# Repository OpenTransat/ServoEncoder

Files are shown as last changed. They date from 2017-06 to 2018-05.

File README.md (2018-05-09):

# ServoEncoder
Controls a motor by evaluating position feedback from a magnetic encoder

## Features

* Based on Atmega328P @ 2 MHz

* Absolute magnetic rotary encoder EMS22A is mounted on the PCB

* Used with JGY-2838 or a similar motor controlled by a two-wire interface

* The two-wire output can be used as serial RX/TX for debugging

* One can use a stepper motor by connecting the two-wire output to a stepper motor driver

* PWM input like a typical servo or serial input (serial version has been chosen as it's more precise than reading the pulse length)

* It provides a feedback to the main controller to determine if the motor is overloaded or stuck

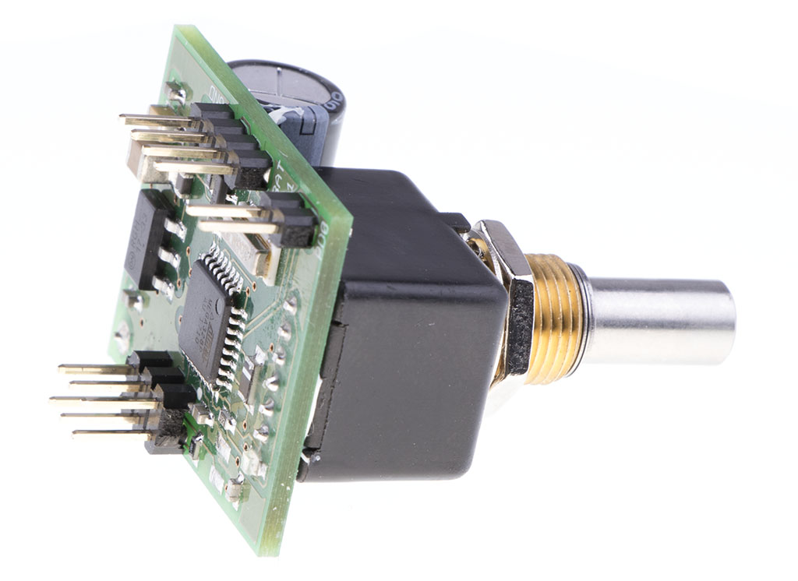
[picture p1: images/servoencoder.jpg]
ServoEncoder PCB


It has been designed as a robust solution for steering the rudder on autonomous boat. The life span has been tested with a worm geared motor JGY-2838.

Ongoing test: 2 million cycles

## Video: Testing worm drive life span

Testing worm drive life span (https://www.youtube.com/watch?v=ynh-ik3KGtM)

## Video: The actual application

Rudder control: Worm geared motor with a position feedback (https://www.youtube.com/watch?v=95Na8EOg1Mo)

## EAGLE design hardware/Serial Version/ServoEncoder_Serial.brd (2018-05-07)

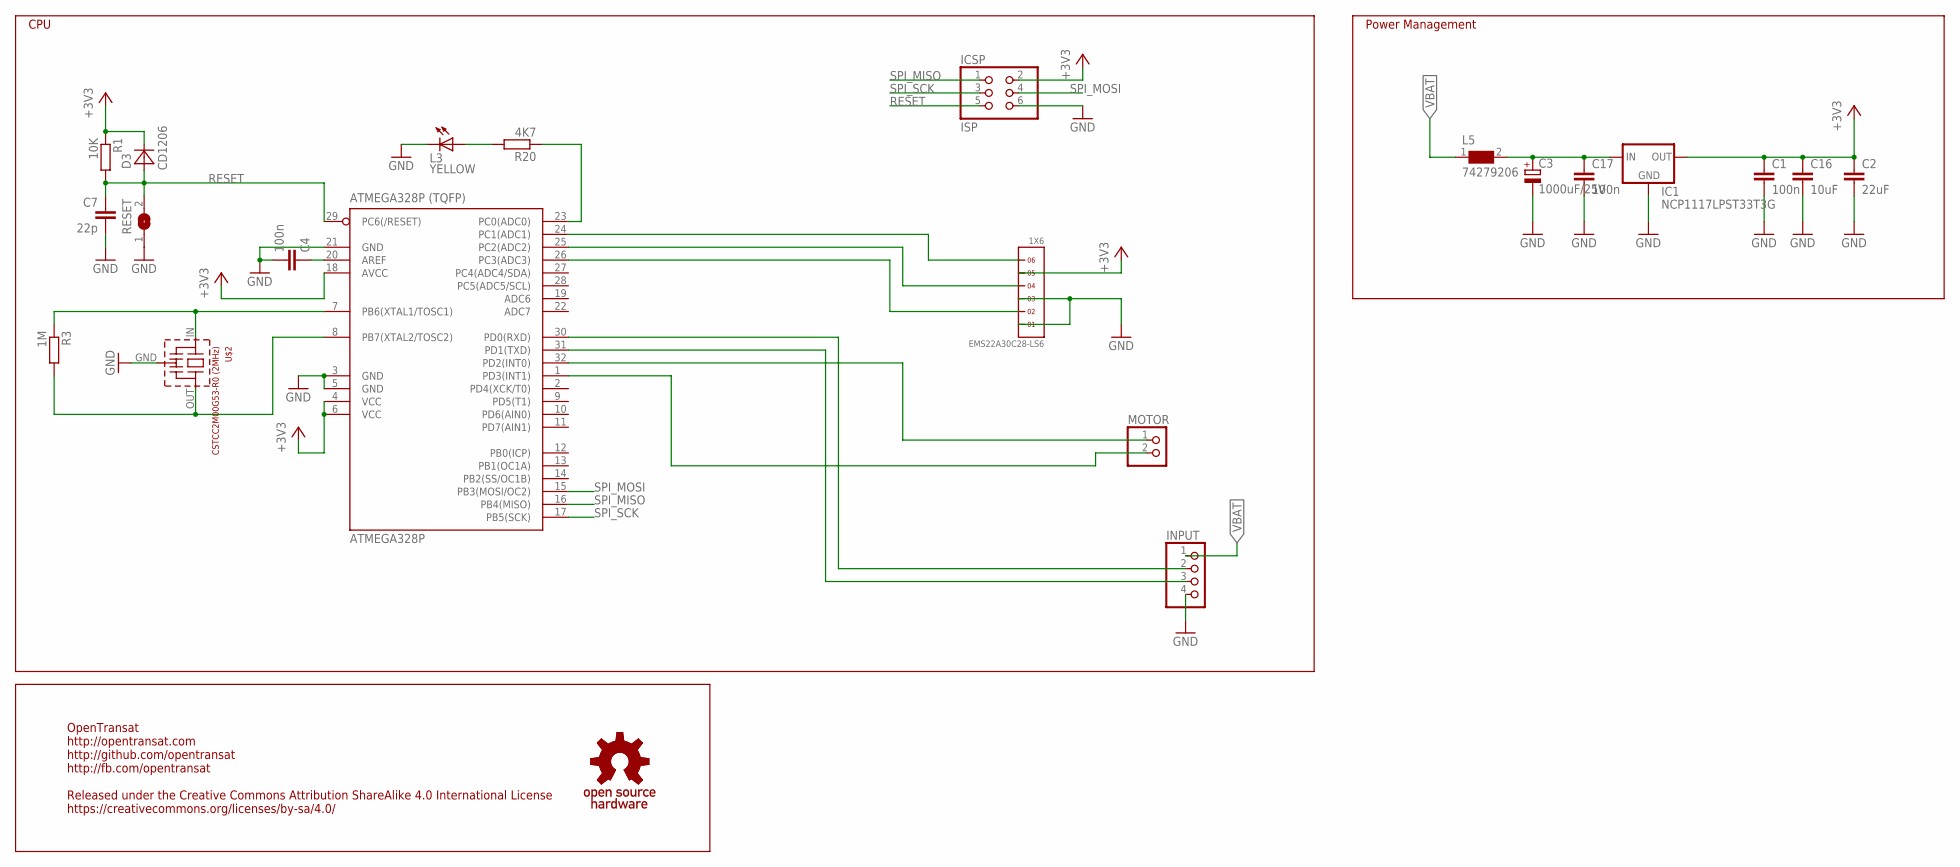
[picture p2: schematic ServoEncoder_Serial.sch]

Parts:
ATMEGA328P: ATMEGA328P (TQFP); TQFP32-08
C1, C4, C17: 100n; C0603
C2: 22uF; C1210
C3: 1000uF/25V; E5-10,5
C7: 22p; C0603
C16: 10uF; C1206
D3: CD1206; R1206
EMS22A30C28-LS6: 1X6
IC1: NCP1117LPST33T3G; SOT223
ICSP: ISP; 2X03
INPUT: PINHD-1X4; 1X04
L3: YELLOW; CHIPLED_0805
L5: 74279206; 0805
MOTOR: PINHD-1X2; 1X02
R1: 10K; R0603
R3: 1M; R0603
R20: 4K7; R0603
RESET: SJW
U$1: OSHW_S; OSHWS
U$2: CSTCC2M00G53-R0 (2MHz); CSTCC

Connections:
+3V3: ATMEGA328P.4 (VCC), ATMEGA328P.6 (VCC), ATMEGA328P.18 (AVCC), C1.1, C2.1, C16.1, D3.2 (C), EMS22A30C28-LS6.5, IC1.2 (OUT), IC1.4 (OUT), ICSP.2, R1.1
AREF: ATMEGA328P.20 (AREF), C4.1
GND: ATMEGA328P.3 (GND), ATMEGA328P.5 (GND), ATMEGA328P.21 (GND), C1.2, C2.2, C3.-, C4.2, C7.2, C16.2, C17.2, EMS22A30C28-LS6.1, EMS22A30C28-LS6.3, IC1.1 (GND), ICSP.6, INPUT.4, L3.C, RESET.1, U$2.GND
L13: ATMEGA328P.23 (PC0(ADC0)), R20.1
unnamed: C3.+, C17.1, IC1.3 (IN), L5.2
unnamed: ATMEGA328P.30 (PD0(RXD)), INPUT.2
unnamed: L3.A, R20.2
unnamed: ATMEGA328P.31 (PD1(TXD)), INPUT.3
unnamed: ATMEGA328P.1 (PD3(INT1)), MOTOR.2
unnamed: ATMEGA328P.24 (PC1(ADC1)), EMS22A30C28-LS6.6
unnamed: ATMEGA328P.25 (PC2(ADC2)), EMS22A30C28-LS6.4
unnamed: ATMEGA328P.26 (PC3(ADC3)), EMS22A30C28-LS6.2
unnamed: ATMEGA328P.32 (PD2(INT0)), MOTOR.1
RESET: ATMEGA328P.29 (PC6(/RESET)), C7.1, D3.1 (A), ICSP.5, R1.2, RESET.2
SPI_MISO: ATMEGA328P.16 (PB4(MISO)), ICSP.1
SPI_MOSI: ATMEGA328P.15 (PB3(MOSI/OC2)), ICSP.4
SPI_SCK: ATMEGA328P.17 (PB5(SCK)), ICSP.3
VBAT: INPUT.1, L5.1
XTAL1: ATMEGA328P.8 (PB7(XTAL2/TOSC2)), R3.2, U$2.OUT
XTAL2: ATMEGA328P.7 (PB6(XTAL1/TOSC1)), R3.1, U$2.IN

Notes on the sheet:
OpenTransat http://opentransat.com http://github.com/opentransat http://fb.com/opentransat Released under the Creative Commons Attribution ShareAlike 4.0 International License https://creativecommons.org/licenses/by-sa/4.0/
Power Management
CPU

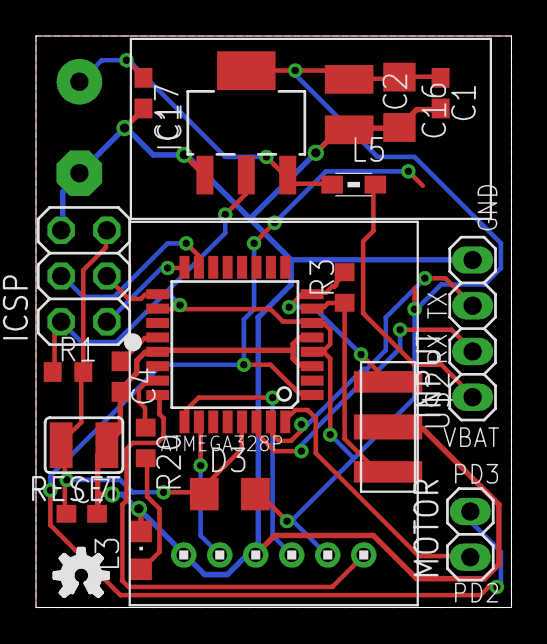
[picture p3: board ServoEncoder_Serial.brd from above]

Board: 2 copper layers, 26.4 x 31.8 mm, 22 parts (1 on the bottom side), 20 nets.

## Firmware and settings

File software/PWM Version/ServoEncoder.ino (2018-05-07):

/*
ServoEncoder
https://github.com/OpenTransat/ServoEncoder

Released under the Creative Commons Attribution ShareAlike 4.0 International License
https://creativecommons.org/licenses/by-sa/4.0/
*/

#define SERIAL_DEBUG //switch between serial debug and motor
#define LED 14 //PC0
#define PIN_CS 15 //PC1, EMS:6
#define PIN_CLK 17 //PC3, EMS:2
#define PIN_DO 16 //PC2, EMS:4
#define PIN_ON 0 //PD0 = Serial RXD, active LOW
#define PIN_REV 1 //PD1 = Serial TXD, active LOW
#define PIN_PWM 2 //PD2
#define PIN_FB 3 //PD3
#define ENC_ZERO 127
#define ENC_MAXDIF 100
#define ENC_MIN (ENC_ZERO - ENC_MAXDIF) //max left
#define ENC_MAX (ENC_ZERO + ENC_MAXDIF) //max right
#define MINCHANGE 0 //minimum PWM change to prevent flickering, 32 is a typical measurement error
#define CORRECTION_LEFT (+11)
#define CORRECTION_RIGHT (-10)

#define PWM_PULSES 3
#define PWM_VALID_THRESHOLD 65 //all PWM_PULSES pulses in the pwm_pulse[] array must be equal within the PWM_VALID_THRESHOLD
volatile unsigned long pwm_timer_start = 0;
volatile unsigned int pwm_pulse[PWM_PULSES];
volatile unsigned char pwm_index = 0;
#define PWM_TIMEOUT 2500

int pulse;
int enc_goto;

void calcRC() { //blocking max 2.5ms
  if(digitalRead(PIN_PWM) == HIGH) { 
    pwm_timer_start = micros();
    unsigned int pwm_length;
    while(digitalRead(PIN_PWM) == HIGH) {
      pwm_length = (unsigned int)(micros() - pwm_timer_start); //negative number converted OK on micros() overflow
      if (pwm_length > PWM_TIMEOUT) //timeout
        return;
    }
    pwm_index = (++pwm_index) % PWM_PULSES;
    pwm_pulse[pwm_index] = (unsigned int)(micros() - pwm_timer_start);
  }
}

/*
void calcRC() { //non-blocking
  if(digitalRead(PIN_PWM) == HIGH) { 
    pwm_timer_start = micros();
  }
  else { 
    if(pwm_timer_start != 0) {
      pwm_index = (++pwm_index) % PWM_PULSES;
      pwm_pulse[pwm_index] = (unsigned int)(micros() - pwm_timer_start); //negative number converted OK on micros() overflow
      pwm_timer_start = 0;
    }
  }
}
*/

void setup() {
  pinMode(LED, OUTPUT);

  #ifdef SERIAL_DEBUG
    Serial.begin(9600); //9600 supported for 2MHz
  #else
    pinMode(PIN_ON, OUTPUT);
    digitalWrite(PIN_ON, HIGH);
    pinMode(PIN_REV, OUTPUT);
    digitalWrite(PIN_REV, HIGH);
  #endif

  pinMode(PIN_CS, OUTPUT);
  digitalWrite(PIN_CS, LOW);
  pinMode(PIN_CLK, OUTPUT);
  digitalWrite(PIN_CLK, HIGH);
  pinMode(PIN_DO, INPUT);

  pinMode(PIN_PWM, INPUT);
  pinMode(PIN_FB, OUTPUT);
  digitalWrite(PIN_FB, LOW);
  attachInterrupt(digitalPinToInterrupt(PIN_PWM), calcRC, CHANGE);
}

int enc_read() { //output: 0..1023, -1 = parity error
  digitalWrite(PIN_CS, HIGH);
  delayMicroseconds(1);
  digitalWrite(PIN_CS, LOW);
  byte b[16];
  int pos = 0;
  byte parity = 0;

  for (int i = 0; i < 16; i++) {
    digitalWrite(PIN_CLK, LOW);
    delayMicroseconds(1);
    digitalWrite(PIN_CLK, HIGH);
    b[i] = digitalRead(PIN_DO) == HIGH ? 1 : 0;

    if (i < 15)
      parity += b[i];
  }

  parity %= 2;

  if (b[15] == parity) {
    for (int i = 0; i < 10; i++) {
      pos += b[i] * (1 << 10-(i+1));
    }
    digitalWrite(PIN_CS, LOW);
    return pos;
  }
  digitalWrite(PIN_CS, LOW);
  return -1;
}

bool validPulse() {
  for (int i = 0; i < PWM_PULSES; i++) {
    if (abs((int)pwm_pulse[i] - (int)pwm_pulse[(i+1)%PWM_PULSES]) > PWM_VALID_THRESHOLD) {
      return false;
    }
  }
  return true;
}

bool isNewPulse() {
  if (!validPulse())
    return false;
  pulse = pwm_pulse[PWM_PULSES-1]; //save pwm_pulse from interrupts
//  pulse = ((millis() / 10000) % 4) * 500 + 1000; if (pulse > 2000) pulse = 1500; //simulation

  static int prev_pulse;

  #ifdef SERIAL_DEBUG
//    Serial.print(pulse);
  #endif

  if (pulse < 900 || pulse > 2100) { //bad pulse
    return false;
  }

  if (pulse < prev_pulse - MINCHANGE || pulse > prev_pulse + MINCHANGE) { //pulse is outside the safe interval
    prev_pulse = pulse;
    return true;
  }
  
  return false;
}

enum tstate {
  STATE_IDLE,
  STATE_RUNNING,
  STATE_NEWPULSE //move interrupted by a new pulse
};

tstate state = STATE_IDLE;

void loop() {
  if (isNewPulse() || state != STATE_IDLE) {
    int enc_goto = map(pulse, 1000, 2000, ENC_MIN, ENC_MAX);
    enc_goto = max(enc_goto, ENC_MIN);
    enc_goto = min(enc_goto, ENC_MAX);
    int enc_pos = enc_read();
    if (enc_pos > 0) { //encoder parity check OK
      #ifdef SERIAL_DEBUG
        Serial.print(pulse);
        Serial.print("\t");
        Serial.print(enc_goto);
        Serial.print("\t");
        Serial.print(enc_pos);
      #endif
      if (enc_pos > enc_goto) { //turn left
        state = STATE_RUNNING;
        #ifdef SERIAL_DEBUG
          Serial.println("\tturn left");
        #else
          motor_left();
        #endif
        while ((enc_pos = enc_read()) > enc_goto + CORRECTION_LEFT) {
          /*if (isNewPulse()) { //TO BE TESTED
            #ifdef SERIAL_DEBUG
              Serial.println("Interrupted by a new pulse");
            #endif
            state = STATE_NEWPULSE;
            break;
          }*/
        }
        if (state != STATE_NEWPULSE) {
          #ifdef SERIAL_DEBUG
            Serial.println("Stop");
          #else
            motor_stop();
          #endif        
          state = STATE_IDLE;
        }
      }
      else if (enc_pos < enc_goto) { //turn right
        state = STATE_RUNNING;
        #ifdef SERIAL_DEBUG
          Serial.println("\tturn right");
        #else
          motor_right();
        #endif
        while ((enc_pos = enc_read()) < enc_goto + CORRECTION_RIGHT) {
          /*if (isNewPulse()) { //TO BE TESTED
            #ifdef SERIAL_DEBUG
              Serial.println("Interrupted by a new pulse");
            #endif
            state = STATE_NEWPULSE;
            break;
          }*/
        }
        if (state != STATE_NEWPULSE) {
          #ifdef SERIAL_DEBUG
            Serial.println("Stop");
          #else
            motor_stop();
          #endif        
          state = STATE_IDLE;
        }
      }
      else { //equal position => stop the motor
        #ifdef SERIAL_DEBUG
          Serial.println("Stop");
        #else
          motor_stop();
        #endif
        state = STATE_IDLE;
      }
    }
    else { //bad encoder parity check => stop the motor
      #ifdef SERIAL_DEBUG
        Serial.println("bad parity");
      #else
        motor_stop();
      #endif
      state = STATE_IDLE;      
    }
  }
}

void motor_stop() {
  digitalWrite(PIN_ON, HIGH);
  digitalWrite(PIN_REV, HIGH);
}

void motor_right() {
  digitalWrite(PIN_REV, HIGH);
  digitalWrite(PIN_ON, LOW);
}

void motor_left() {
  digitalWrite(PIN_REV, LOW);
  digitalWrite(PIN_ON, LOW);
}

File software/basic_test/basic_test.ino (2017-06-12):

/*
ServoEncoder
TEST PROGRAM

https://github.com/OpenTransat/ServoEncoder

Released under the Creative Commons Attribution ShareAlike 4.0 International License
https://creativecommons.org/licenses/by-sa/4.0/
*/

#define SERIAL_DEBUG //switch between serial debug and motor
#define LED 14 //PC0
#define PIN_CS 15 //PC1, EMS:6
#define PIN_CLK 17 //PC3, EMS:2
#define PIN_DO 16 //PC2, EMS:4
#define PIN_ON 0 //PD0
#define PIN_REV 1 //PD1
#define PIN_PWM 2 //PD2
#define PIN_FB 3 //PD3
#define ZERO_POS 30
#define DELTA 70

void setup() {
  pinMode(LED, OUTPUT);

  pinMode(PIN_CS, OUTPUT);
  digitalWrite(PIN_CS, HIGH);
  pinMode(PIN_CLK, OUTPUT);
  digitalWrite(PIN_CLK, HIGH);
  pinMode(PIN_DO, INPUT);

  #ifdef SERIAL_DEBUG
    Serial.begin(9600); //9600 supported for 2MHz
  #else
    pinMode(PIN_ON, OUTPUT);
    digitalWrite(PIN_ON, HIGH);
    pinMode(PIN_REV, OUTPUT);
    digitalWrite(PIN_REV, HIGH);
  #endif
}

byte dir = 1;

void gotopos(int where, int where_stop) {
  digitalWrite(PIN_CS, LOW);
  delayMicroseconds(1);  
  byte b[16];
  int pos = 0;
  byte parity = 0;

  for (int i = 0; i < 16; i++) {
    digitalWrite(PIN_CLK, LOW);
    delayMicroseconds(1);
    digitalWrite(PIN_CLK, HIGH);
    b[i] = digitalRead(PIN_DO) == HIGH ? 1 : 0;

    if (i < 15)
      parity += b[i];
  }

  parity %= 2;

  if (b[15] == parity) {

    for (int i = 0; i < 10; i++) {
      pos += b[i] * (1 << 10-(i+1));
    }

    pos = (pos - ZERO_POS) % 1024;
    if (pos > 512)
      pos = pos - 1024;

    if (pos < where && pos < where_stop) {
      #ifdef SERIAL_DEBUG
        Serial.println("go forward");
      #else
        digitalWrite(PIN_ON, LOW);
        digitalWrite(PIN_REV, LOW);
      #endif
    } else if (pos > where && pos > where_stop) {
      #ifdef SERIAL_DEBUG
        Serial.println("go back");
      #else
        digitalWrite(PIN_ON, LOW);
        digitalWrite(PIN_REV, HIGH);
      #endif
    }
    else if (pos > where && pos < where_stop) {
      #ifdef SERIAL_DEBUG
      #else
        digitalWrite(PIN_ON, HIGH);      
      #endif
    }
    else if (pos < where && pos > where_stop) {
      #ifdef SERIAL_DEBUG
      #else
        digitalWrite(PIN_ON, HIGH);      
      #endif
    }
  
    #ifdef SERIAL_DEBUG
      Serial.println(pos);
    #endif
  }
  else {
    digitalWrite(PIN_CS, HIGH);
    #ifdef SERIAL_DEBUG
      Serial.println("parity error!");
    #else
      digitalWrite(PIN_ON, HIGH);
      digitalWrite(PIN_REV, HIGH);
    #endif
    delay(1000);
  }
  digitalWrite(PIN_CS, HIGH);
}

unsigned long previousMillis = 0;
#define INTERVAL 1000UL
byte state = 0;

void loop() {
  unsigned long currentMillis = millis();

  if (currentMillis < previousMillis) { //millis() overflow
    previousMillis = 0;
  }
  
  if (currentMillis - previousMillis >= INTERVAL) {
    previousMillis = currentMillis;
    state = 1 - state;
  }

  if (state)
    gotopos(DELTA, DELTA+50);
  else
    gotopos(-DELTA, -DELTA-50);
}

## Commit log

2018-05-07 Rename hardware/ServoEncoder.sch to hardware/PWM Version/ServoEncoder.sch
    [ServoEncoder.sch]
2018-05-07 Rename hardware/ServoEncoder.brd to hardware/PWM Version/ServoEncoder.brd
    [ServoEncoder.brd]
2018-05-07 Rename software/ServoEncoder.ino to software/PWM Version/ServoEncoder.ino
2018-05-07 Rename software/ServoEncoder_Serial.ino to software/Serial Version/ServoEncoder_Serial.ino

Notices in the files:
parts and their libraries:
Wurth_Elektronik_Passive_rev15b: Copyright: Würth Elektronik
